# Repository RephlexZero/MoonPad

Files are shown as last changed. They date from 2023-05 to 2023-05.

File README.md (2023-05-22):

KiCAD design files for the RP2040 based analogue 2k keyboard.

Online viewing available here:

https://kicanvas.org/?github=https%3A%2F%2Fgithub.com%2FRephlexZero%2FMoonPad%2Ftree%2Fmaster




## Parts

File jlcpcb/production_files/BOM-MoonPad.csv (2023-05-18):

Comment | Designator | Footprint | LCSC
Reset | SW1 | SW_SPST_TL3342 | C115351
1k | R1,R5 | R_0402_1005Metric | C11702
100n | C11,C12,C13,C14,C15,C16,C17,C18,C19,C20,C21,C22,C23,C24,C25,C26,C27,C5,C6,C7,C9 | C_0402_1005Metric | C1525
27p | C2,C3 | C_0402_1005Metric | C1557
USB-C 2.0 Receptacle | J3 | USB_C_Receptacle_HRO_TYPE-C-31-M-12 | C165948
RP2040 | U3 | RP2040-QFN-56 | C2040
27 | R3,R4 | R_0402_1005Metric | C25100
470 | RLED1,RLED2 | R_0402_1005Metric | C25117
10k | R7,R8 | R_0402_1005Metric | C25744
5.1k | R2,R6 | R_0402_1005Metric | C25905
1.1A | F1 | Fuse_1206_3216Metric | C2760273
PRTR5V0U2X | D7 | SOT-143 | C2827688
1u | C1,C4 | C_0805_2012Metric | C28323
W25Q16JVUXIQ | IC1 | SON50P300X200X60-9N | C2843335
SLSS49E-3 | U4,U5 | SOT-23 | C2904393
JGHC S3212000181080 | Y1 | Crystal_SMD_3225-4Pin_3.2x2.5mm | C390764
AP2112K-3.3 | U6 | SOT-23-5 | C51118
SK6812MINI-E | D1,D4 | MX_SK6812MINI-E_REV | C5149201
SK6812MINI | D2,D3,D5,D6 | LED_SK6812MINI-B-012_3.7x3.5mm_P1.1mm | C5183448
1u | C10,C8 | C_0402_1005Metric | C52923

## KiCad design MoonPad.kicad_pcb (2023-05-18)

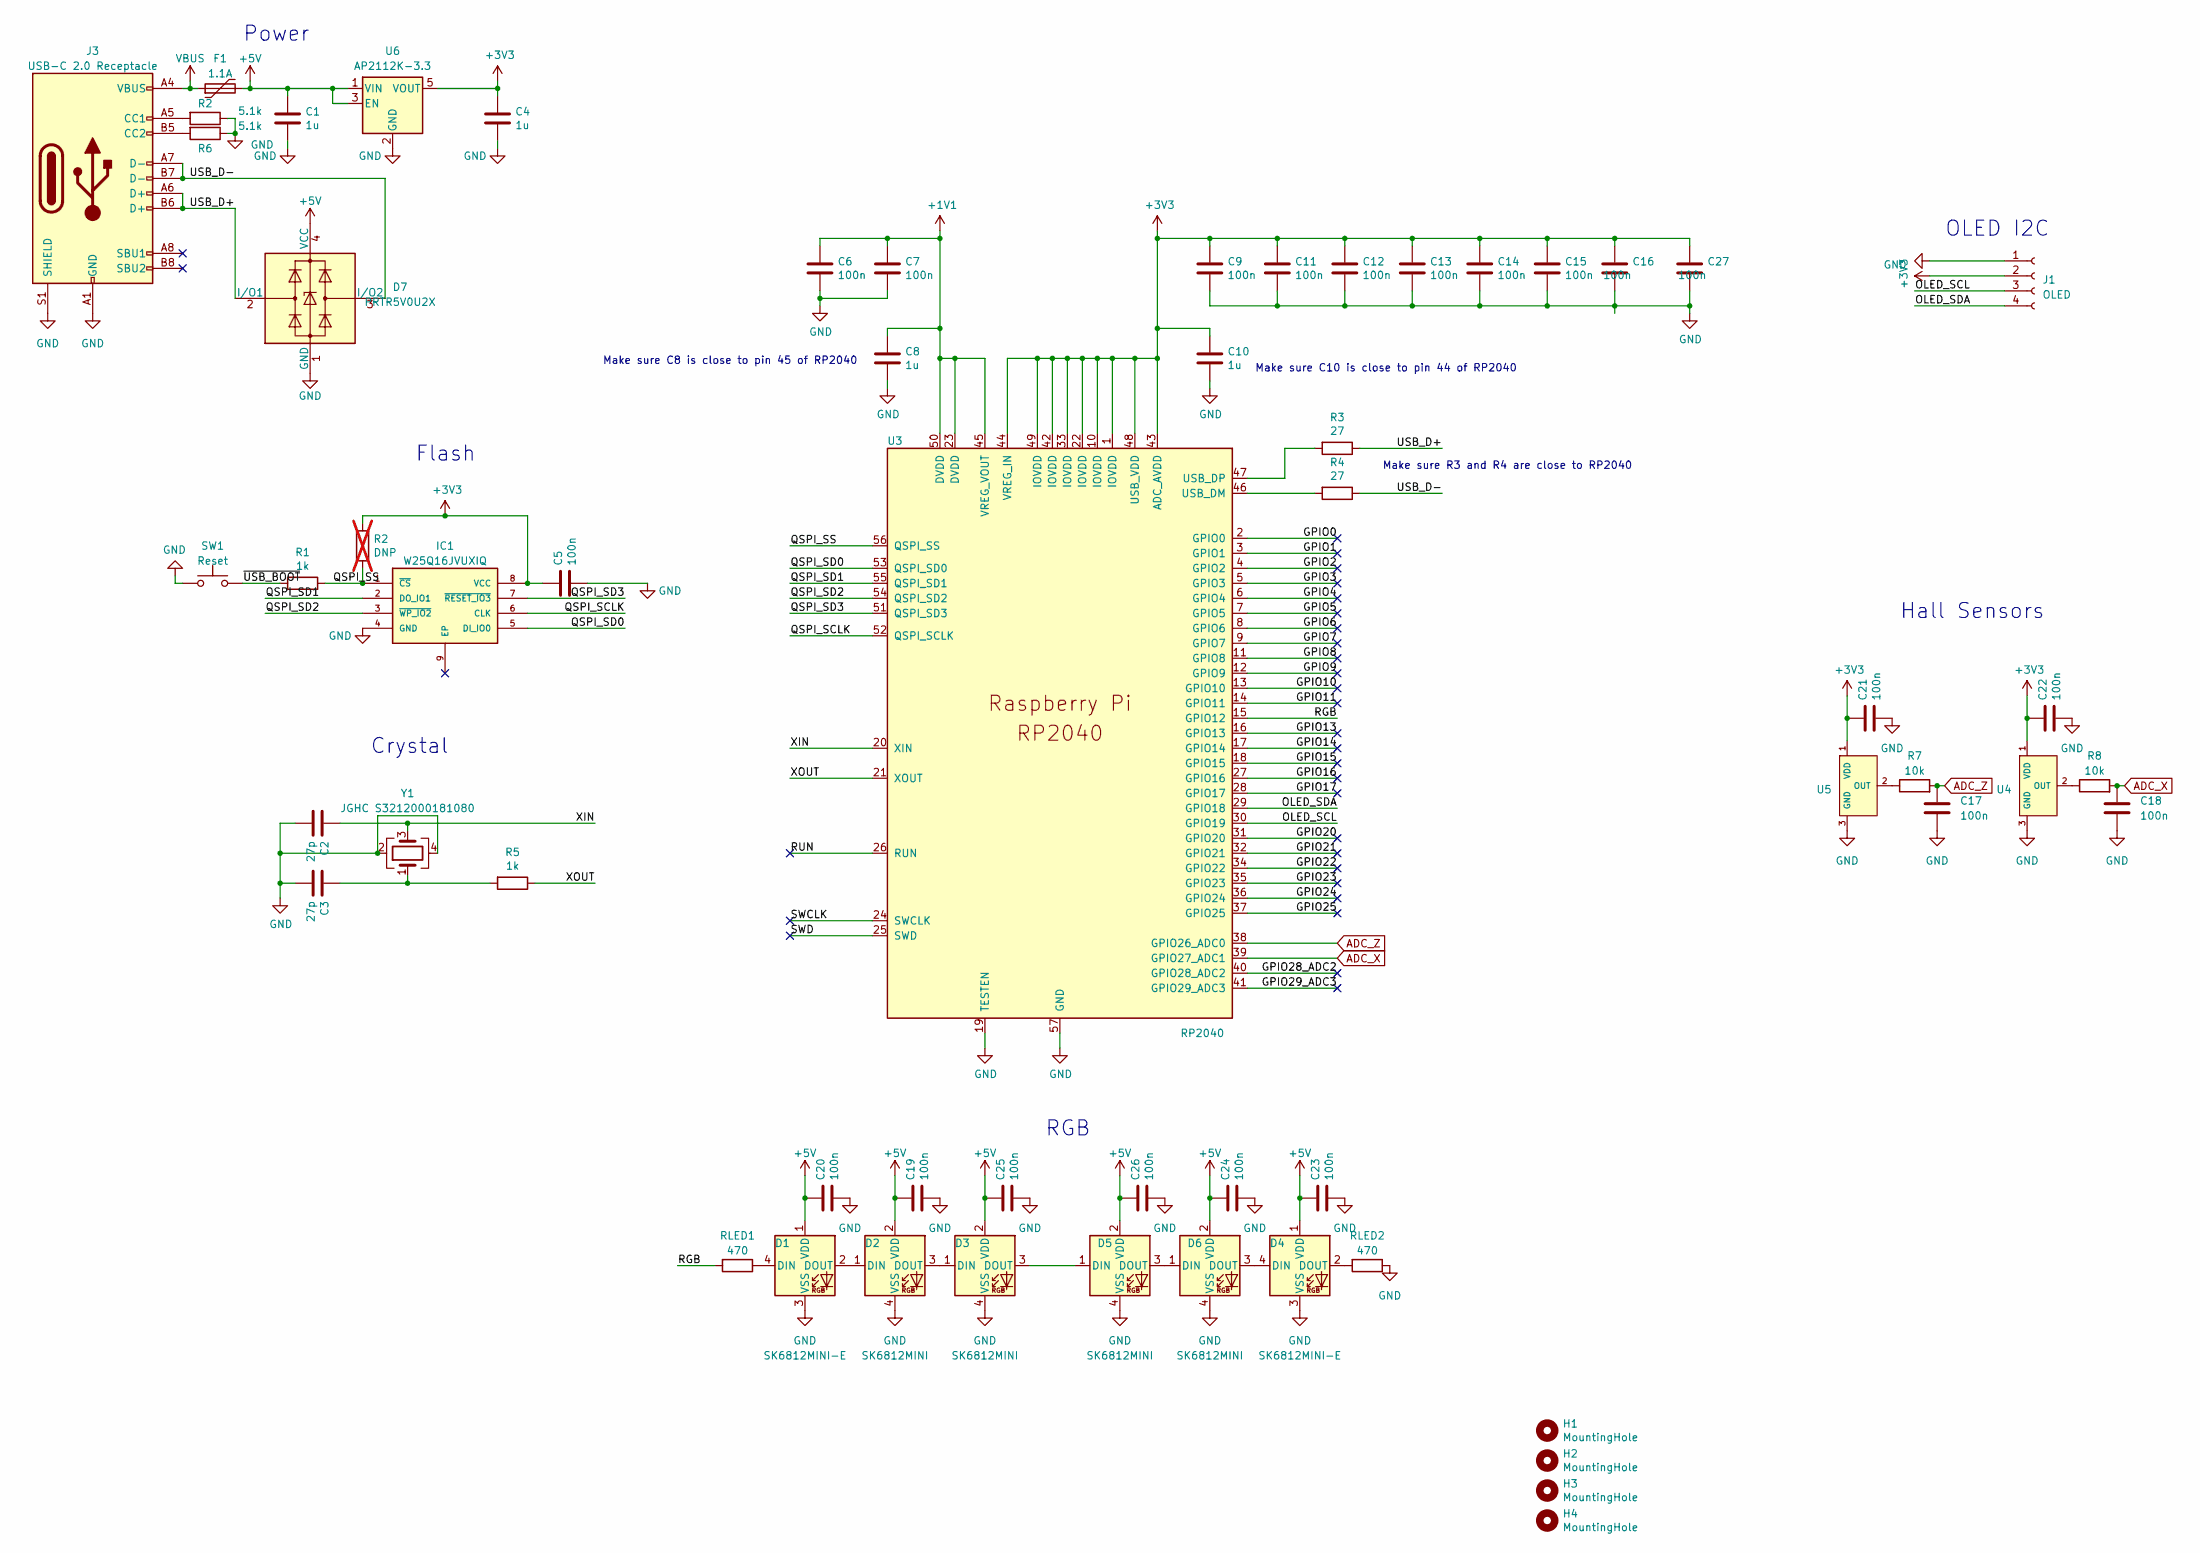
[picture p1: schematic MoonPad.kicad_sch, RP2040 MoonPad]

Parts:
C1, C4: 1u; C_0805_2012Metric; LCSC Part C28323
C2, C3: 27p; C_0402_1005Metric; LCSC C86287
C5, C6, C7, C9, C11, C12, C13, C14, C15, C16, C19, C20, C21, C22, C23, C24, C25, C26, C27: 100n; C_0402_1005Metric; LCSC C1525
C8, C10: 1u; C_0402_1005Metric; LCSC C52923
C17, C18: 100n; C_0402_1005Metric; LCSC C5139511
D1, D4: SK6812MINI-E; MX_SK6812MINI-E_REV; LCSC Part C5149201
D2, D3, D5, D6: SK6812MINI; LED_SK6812MINI-B-012_3.7x3.5mm_P1.1mm; LCSC Part C5183448
D7: PRTR5V0U2X; SOT-143; LCSC C2827688
F1: 1.1A; Fuse_1206_3216Metric; LCSC C2760273
H1, H2, H3, H4: MountingHole; MountingHole_2.2mm_M2
IC1: W25Q16JVUXIQ; SON50P300X200X60-9N; MANUFACTURER_PART_NUMBER W25Q16JVUXIQ; LCSC Part C2843335
J1: OLED; PinHeader_1x04_P2.54mm_Vertical
J3: USB-C 2.0 Receptacle; USB_C_Receptacle_HRO_TYPE-C-31-M-12; LCSC Part C165948
R1, R5: 1k; R_0402_1005Metric; LCSC Part C25543
R2: DNP; C_0402_1005Metric; LCSC C25905; not fitted
R3, R4: 27; R_0402_1005Metric; LCSC Part C25100
R6: 5.1k; R_0402_1005Metric; LCSC C25905
R7, R8: 10k; R_0402_1005Metric; LCSC C25744
RLED1, RLED2: 470; R_0402_1005Metric; LCSC Part C2828857
SW1: Reset; SW_SPST_TL3342; LCSC Part C115351
U3: RP2040; RP2040-QFN-56; LCSC Part C2040
U4, U5: SLSS49E-3; SOT-23; LCSC Part C2904393
U6: AP2112K-3.3; SOT-23-5; LCSC C51118
Y1: JGHC S3212000181080; Crystal_SMD_3225-4Pin_3.2x2.5mm; LCSC Part C390764

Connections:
+1V1: C6.1, C7.1, C8.1, U3.23 (DVDD), U3.45 (VREG_VOUT), U3.50 (DVDD)
+5V: C1.1, C19.1, C20.1, C23.1, C24.1, C25.1, C26.1, D1.1 (VDD), D2.2 (VDD), D3.2 (VDD), D4.1 (VDD), D5.2 (VDD), D6.2 (VDD), D7.4 (VCC), F1.2, U6.1 (VIN), U6.3 (EN)
/GPIO0: U3.2 (GPIO0)
/GPIO1: U3.3 (GPIO1)
/GPIO2: U3.4 (GPIO2)
/GPIO3: U3.5 (GPIO3)
/GPIO4: U3.6 (GPIO4)
/GPIO5: U3.7 (GPIO5)
/GPIO6: U3.8 (GPIO6)
/GPIO7: U3.9 (GPIO7)
/GPIO8: U3.11 (GPIO8)
/GPIO9: U3.12 (GPIO9)
/GPIO10: U3.13 (GPIO10)
/GPIO11: U3.14 (GPIO11)
/GPIO13: U3.16 (GPIO13)
/GPIO14: U3.17 (GPIO14)
/GPIO15: U3.18 (GPIO15)
/GPIO16: U3.27 (GPIO16)
/GPIO17: U3.28 (GPIO17)
/GPIO20: U3.31 (GPIO20)
/GPIO21: U3.32 (GPIO21)
/GPIO22: U3.34 (GPIO22)
/GPIO23: U3.35 (GPIO23)
/GPIO24: U3.36 (GPIO24)
/GPIO25: U3.37 (GPIO25)
/GPIO28_ADC2: U3.40 (GPIO28_ADC2)
/GPIO29_ADC3: U3.41 (GPIO29_ADC3)
/OLED_SCL: J1.3, U3.30 (GPIO19)
/OLED_SDA: J1.4, U3.29 (GPIO18)
/QSPI_SCLK: IC1.6 (CLK), U3.52 (QSPI_SCLK)
/QSPI_SD0: IC1.5 (DI_IO0), U3.53 (QSPI_SD0)
/QSPI_SD1: IC1.2 (DO_IO1), U3.55 (QSPI_SD1)
/QSPI_SD2: IC1.3 (~WP_IO2), U3.54 (QSPI_SD2)
/QSPI_SD3: IC1.7 (~RESET_IO3), U3.51 (QSPI_SD3)
/RGB: RLED1.2, U3.15 (GPIO12)
/RUN: U3.26 (RUN)
/SWCLK: U3.24 (SWCLK)
/SWD: U3.25 (SWD)
/USB_D+: D7.2 (I/O1), J3.A6 (D+), J3.B6 (D+), R3.1
/USB_D-: D7.3 (I/O2), J3.A7 (D-), J3.B7 (D-), R4.1
/XIN: C2.1, U3.20 (XIN), Y1.3
/XOUT: R5.1, U3.21 (XOUT)
/~USB_BOOT: R1.2, SW1.2
ADC_X: C18.1, R8.2, U3.39 (GPIO27_ADC1)
ADC_Z: C17.1, R7.2, U3.38 (GPIO26_ADC0)
unnamed: C3.1, R5.2, Y1.1
unnamed: D1.4 (DIN), RLED1.1
unnamed: D1.2 (DOUT), D2.1 (DIN)
unnamed: D2.3 (DOUT), D3.1 (DIN)
unnamed: D3.3 (DOUT), D5.1 (DIN)
unnamed: D4.4 (DIN), D6.3 (DOUT)
unnamed: D4.2 (DOUT), RLED2.2
unnamed: D5.3 (DOUT), D6.1 (DIN)
unnamed: J3.B5 (CC2), R6.2
unnamed: R4.2, U3.46 (USB_DM)
unnamed: R3.2, U3.47 (USB_DP)
unnamed: R8.1, U4.2 (OUT)
unnamed: R7.1, U5.2 (OUT)
VBUS: F1.1, J3.A4 (VBUS), J3.A9 (VBUS), J3.B4 (VBUS), J3.B9 (VBUS)

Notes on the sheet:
Flash
OLED I2C
Power
Make sure R3 and R4 are close to RP2040
Make sure C10 is close to pin 44 of RP2040
Hall Sensors
Crystal
RGB
Make sure C8 is close to pin 45 of RP2040

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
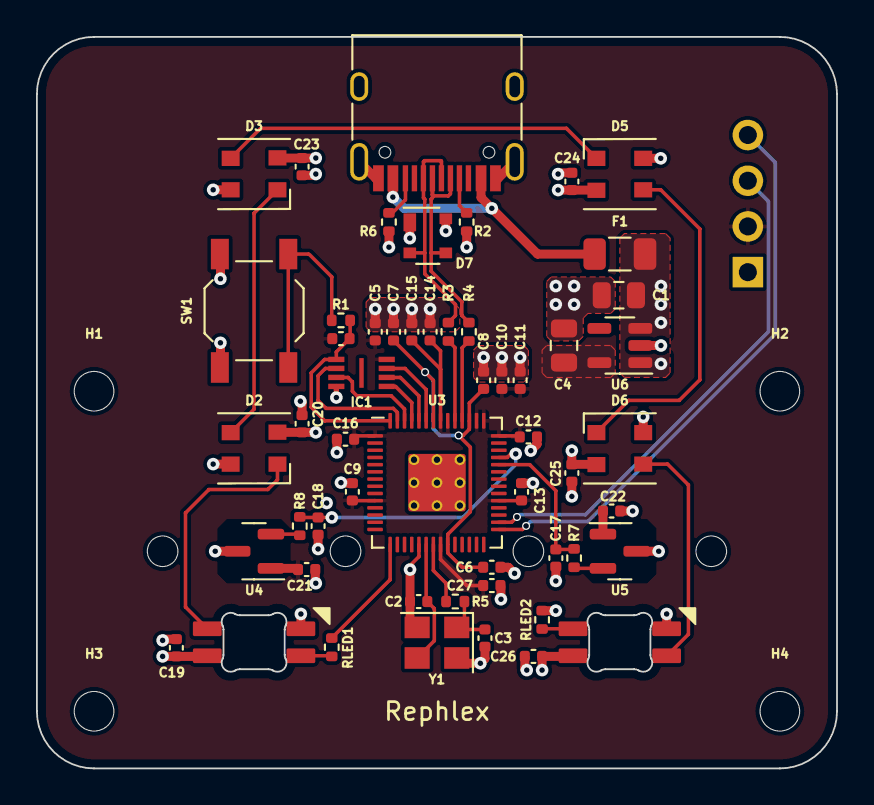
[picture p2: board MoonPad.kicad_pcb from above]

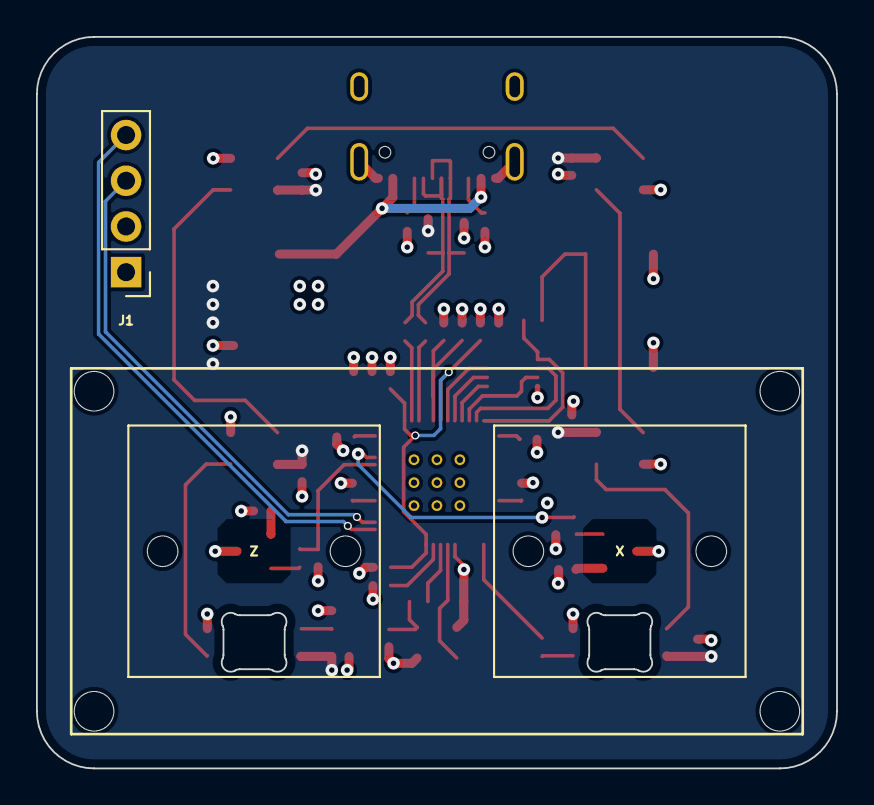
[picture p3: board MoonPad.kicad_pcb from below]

Board: 4 copper layers, 44.5 x 40.6 mm, 61 parts (3 on the bottom side), 35 nets.

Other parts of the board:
R9: DNP; C_0402_1005Metric
X: Wooting_1.00u
Z: Wooting_1.00u

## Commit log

2023-05-11 Added gerbers and drill files
    [MoonPad-B_Cu.gbr, MoonPad-B_Mask.gbr, MoonPad-B_Paste.gbr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]
2023-05-11 Migrate manufacturing files to seperate folder
    [MoonPad-B_Cu.gbr, MoonPad-B_Mask.gbr, MoonPad-B_Paste.gbr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]
2023-05-12 Added ESD Protection
    [MoonPad.csv, MoonPad.kicad_pcb]
2023-05-12 Added fuse
    [MoonPad.kicad_pcb, MoonPad.kicad_sch]
2023-05-13 Added part numbers, some schema adjustments
    [MoonPad.kicad_pcb, MoonPad.kicad_sch]
2023-05-13 Minor layout changes
    [MoonPad.kicad_pcb]
2023-05-13 All part numbers added
    [BOM-MoonPad.csv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]
2023-05-17 Less extended parts
    [BOM-MoonPad.csv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]
2023-05-17 Fixed libraries
    [MoonPad.kicad_pcb, MoonPad.kicad_sch]
2023-05-18 Edited some 3d. Now sent for manufacturing.
    [BOM-MoonPad.csv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]
